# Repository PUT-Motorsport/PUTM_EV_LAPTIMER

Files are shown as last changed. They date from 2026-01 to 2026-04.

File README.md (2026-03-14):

# PUTM EV LAPTIMER

## About
This is standalone laptimer for Formula Student made on ESP32-S3 with ESP-IDF and LVGL. It provides simple way to monitor your lap times during trainings and vehicle tests.

## Features
- Measure lap time using one or two measure gates
- Save lap times on SD card
- Watch lap times on LCD or webpage
- Download .csv files with sorted lap times
- Add penalties from FSG Rules during laptime

## How to use
LCD GUI:
<br/>
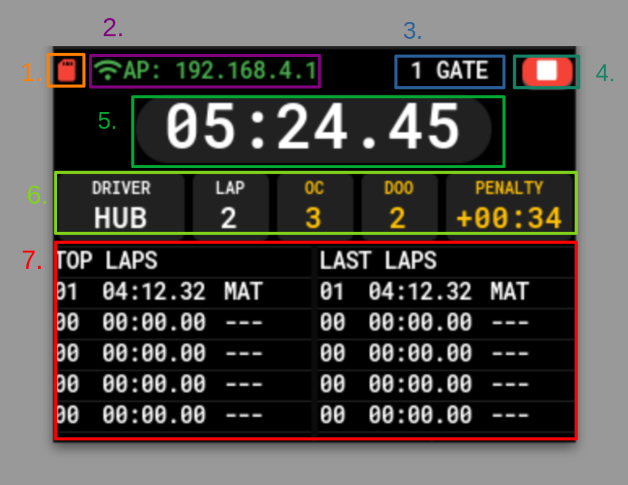
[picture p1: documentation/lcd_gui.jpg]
gui

1. SD card status
   - RED - not initialized
   - GREEN - initialized
2. WIFI status, mode and IP
   - RED - not initialized
   - GREEN - initialized
   - STA - station mode
   -  AP - access point mode
3. Gate mode
   - 1 GATE - like F1 race finish line, next lap starts automatically 
   - 2 GATES - one gate starts lap, second gate ends lap, then timer stops
4. RUN/STOP
   - RED - lap stopped
   - GREEN - lap in progress
5. Current lap time
6. Current lap info
   - DRIVER - tag of current driver
   - LAP - lap count
   - OC - number of FSG OC penalties
   - DOO - number of FSG DOO penalties
   - PENALTY - cumulated penalty time added to current lap time after finishing
7. Lap time lists
   <br/>
Similar interface can be accessed by connecting to a webpage hosted on ip address displayed on LCD. Moreover, on webpage you can download .csv files with lap times and change system configuration settings:
- Gate mode
- Wifi mode
- SSID and password of wifi network
- Date and time
- List of drivers
Those settings can be also changed by inserting SD card with [config file](firmware/main/config.txt)<br/>
## How to install
1. It's recommended to install ESP-IDF for Visual Studio Code with [this guide](https://github.com/espressif/vscode-esp-idf-extension/blob/master/README.md).
2. After cloning repository you should configure ESP-IDF project using
```
idf.py menuconfig
```
in CLI with activated ESP-IDF or 
```
>ESP-IDF: SDK Configuration Editor (Menuconfig)
```
in VSCode Command Palette, pin assignment and some other settings can be set in (Component config)/(PUTM EV Laptimer).
Default pin assignment is for ESP32-S3 and matches shield hardware used in this project.
<br/><br/>
3. Run
```
idf.py build
```
in CLI or
```
>ESP-IDF: Build Your Project
```
in Command Palette to build project
4. Easy way to quickly rebuild and flash project is to use command
```
>ESP-IDF: Build, Flash and Start a Monitor on Your Device
```
also available from VSCode status bar. You will also see program output in CLI. 
<br/>

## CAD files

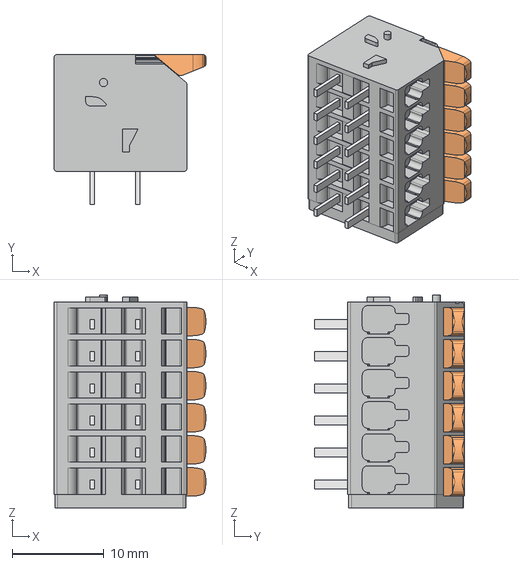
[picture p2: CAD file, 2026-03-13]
hardware/Model/2601-1106.stp
16.6 x 16.4 x 23.2 mm

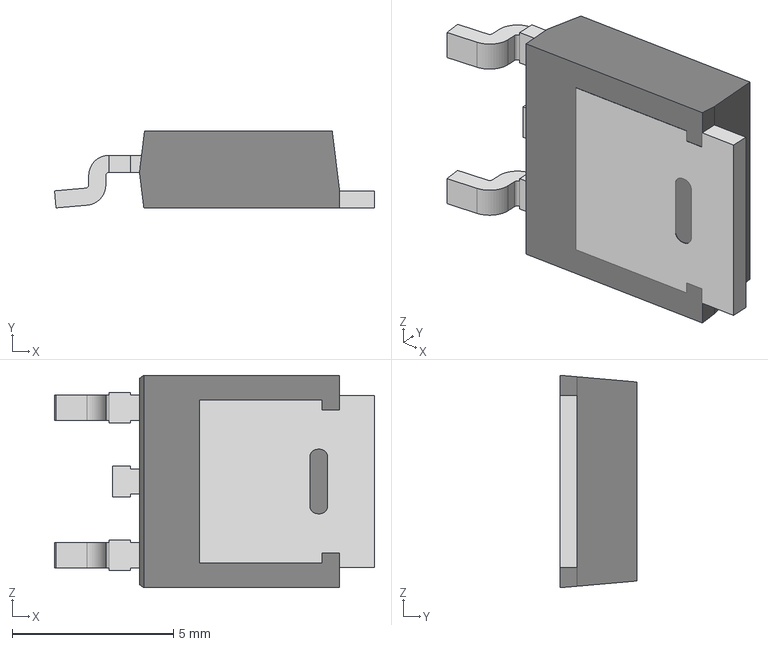
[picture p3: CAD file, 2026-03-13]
hardware/Model/VS-50WQ03FN-M3.stp
9.91 x 2.40 x 6.58 mm

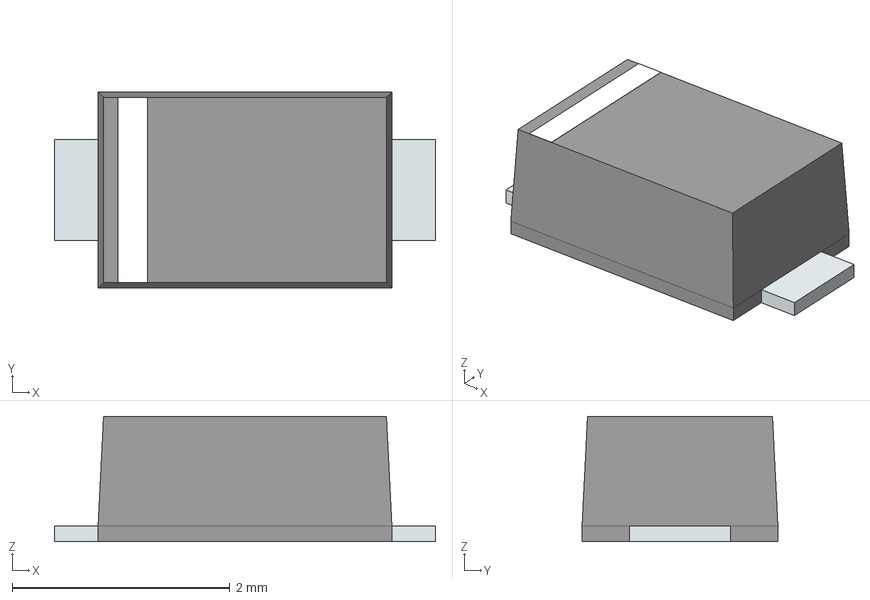
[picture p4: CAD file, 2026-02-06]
hardware/Model/MBR230S1F-7.stp
3.50 x 1.80 x 1.15 mm
PinKIdent
PinK
PinA

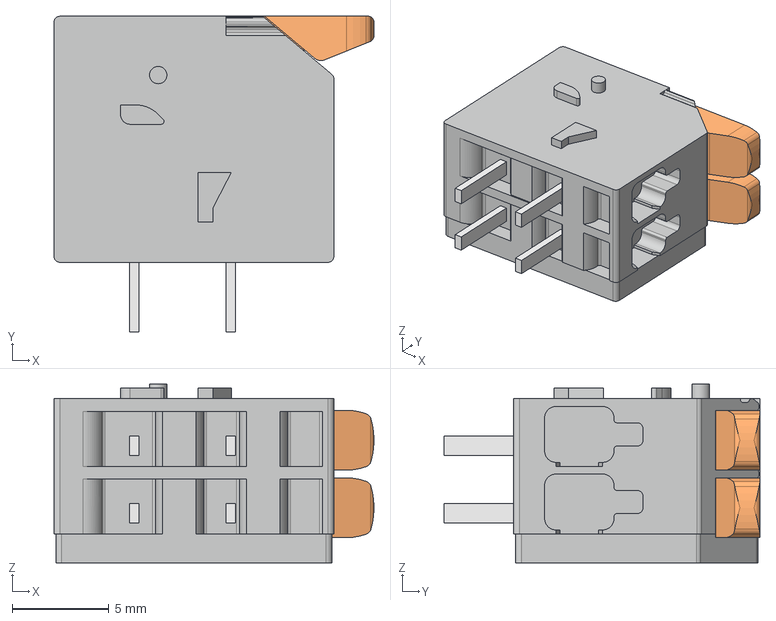
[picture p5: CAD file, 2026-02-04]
hardware/Model/2601-1102.stp
16.6 x 16.4 x 9.25 mm

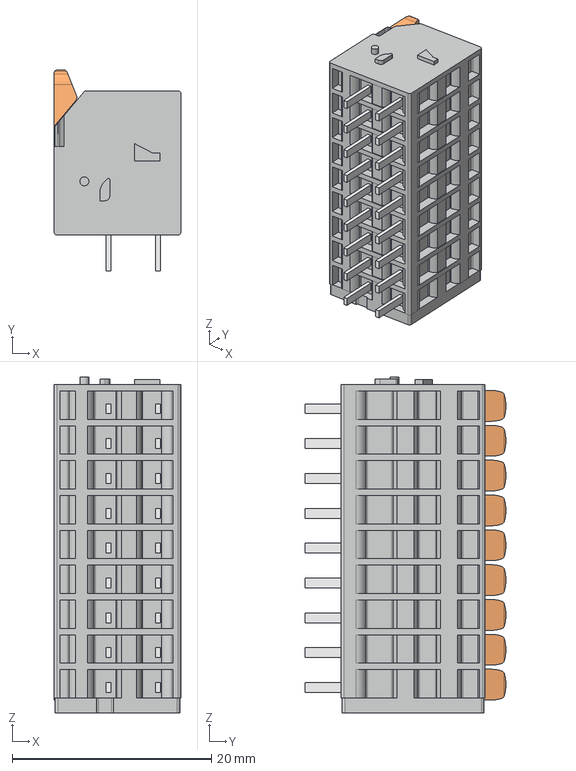
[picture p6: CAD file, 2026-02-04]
hardware/Model/2601-3109.stp
12.8 x 20.2 x 33.8 mm

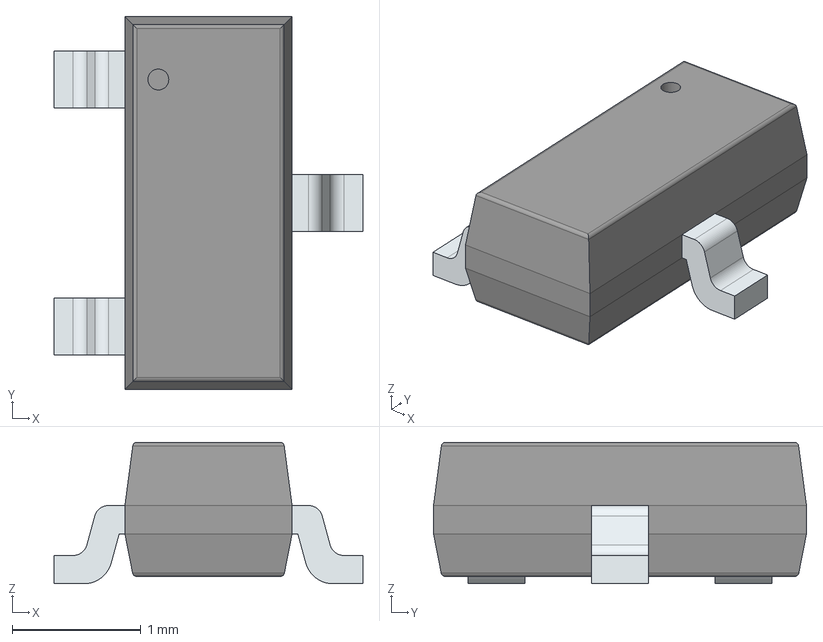
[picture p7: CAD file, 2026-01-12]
hardware/Model/DESD3V3L2BTQ-7.stp
2.40 x 2.90 x 1.10 mm
PinsArrayL
FilletPinR

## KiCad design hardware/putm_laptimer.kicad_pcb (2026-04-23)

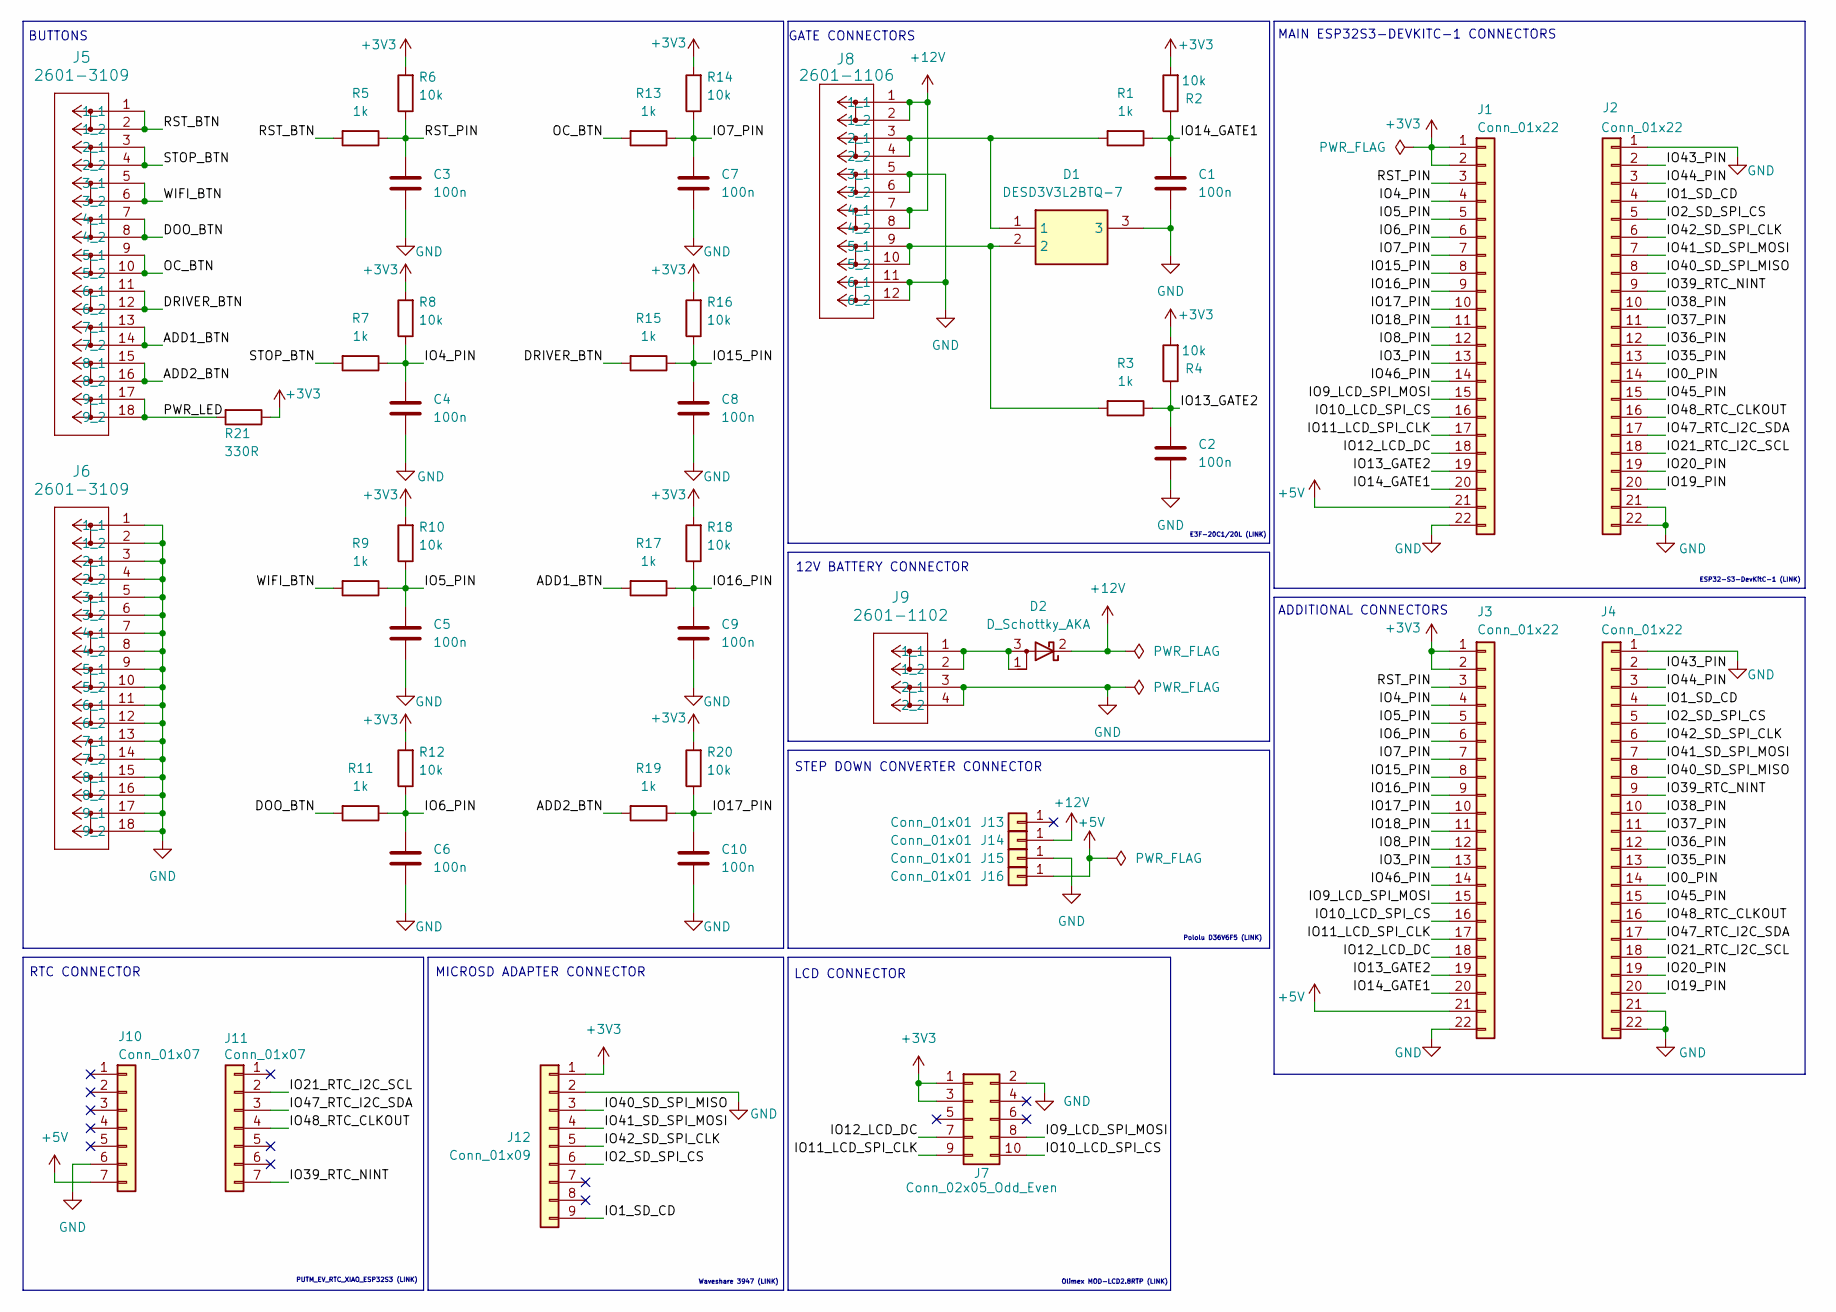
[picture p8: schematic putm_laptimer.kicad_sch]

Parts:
C1, C2, C3, C4, C5, C6, C7, C8, C9, C10: 100n; C_0603_1608Metric; Manufacturer_Part_Number GRM033R6YA104ME14D; Mouser/TME part number 81-GRM33R6YA104ME14D
D1: DESD3V3L2BTQ-7; SOT96P240X110-3N; Manufacturer_Part_Number DESD3V3L2BTQ-7; Mouser/TME part number 621-DESD3V3L2BTQ-7
D2: D_Schottky_AKA; VS50WQ03FNM3; Mouser/TME part number 844-50WQ03FN-M3
J1, J2, J3, J4: Conn_01x22; PinSocket_1x22_P2.54mm_Vertical; Manufacturer_Part_Number DS1023-1*40S21; Mouser/TME part number ZL262-40SG
J5, J6: 2601-3109; CONN9_2601-3109_WAG; Manufacturer_Part_Number 2601-3109; Mouser/TME part number sample
J7: Conn_02x05_Odd_Even; PinHeader_2x05_P2.54mm_Vertical; Manufacturer_Part_Number DS1013-10SSIB1-B-0; Mouser/TME part number ZL231-10PG
J8: 2601-1106; CONN6_2601-1106_WAG; Manufacturer_Part_Number 2601-1106; Mouser/TME part number sample
J9: 2601-1102; CONN2_2601-1102_WAG; Manufacturer_Part_Number 2601-1102; Mouser/TME part number sample
J10, J11: Conn_01x07; PinSocket_1x07_P2.54mm_Vertical; Manufacturer_Part_Number DS1023-1*7S21; Mouser/TME part number ZL262-7SG
J12: Conn_01x09; PinSocket_1x09_P2.54mm_Horizontal; Manufacturer_Part_Number DS1023-1*9S21; Mouser/TME part number ZL262-9SG
J13, J14, J15, J16: Conn_01x01; TestPoint_THTPad_D2.0mm_Drill1.0mm
R1, R3, R5, R7, R9, R11, R13, R15, R17, R19: 1k; R_0603_1608Metric; Manufacturer_Part_Number CR0603-FX-1001ELF; Mouser/TME part number 652-CR0603FX-1001ELF
R2, R4, R6, R8, R10, R12, R14, R16, R18, R20: 10k; R_0603_1608Metric; Manufacturer_Part_Number CR0603-FX-1002ELF; Mouser/TME part number 652-CR0603FX-1002ELF
R21: 330R; R_0603_1608Metric; Manufacturer_Part_Number CR0603-FX-3300ELF; Mouser/TME part number 652-CR0603FX-3300ELF

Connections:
+3V3: J1.1, J1.2, J3.1, J3.2, J7.1, J7.3, J12.1, R2.2, R4.2, R6.2, R8.2, R10.2, R12.2, R14.2, R16.2, R18.2, R20.2, R21.1
+5V: J1.21, J3.21, J10.7, J16.1
+12V: D2.2 (K), J8.1 (1_1), J8.2 (1_2), J8.7 (4_1), J8.8 (4_2), J14.1
/ADD1_BTN: J5.13 (7_1), J5.14 (7_2), R17.2
/ADD2_BTN: J5.15 (8_1), J5.16 (8_2), R19.2
/DOO_BTN: J5.7 (4_1), J5.8 (4_2), R11.2
/DRIVER_BTN: J5.11 (6_1), J5.12 (6_2), R15.2
/IO0_PIN: J2.14, J4.14
/IO1_SD_CD: J2.4, J4.4, J12.9
/IO2_SD_SPI_CS: J2.5, J4.5, J12.6
/IO3_PIN: J1.13, J3.13
/IO4_PIN: C4.1, J1.4, J3.4, R7.1, R8.1
/IO5_PIN: C5.1, J1.5, J3.5, R9.1, R10.1
/IO6_PIN: C6.1, J1.6, J3.6, R11.1, R12.1
/IO7_PIN: C7.1, J1.7, J3.7, R13.1, R14.1
/IO8_PIN: J1.12, J3.12
/IO9_LCD_SPI_MOSI: J1.15, J3.15, J7.8
/IO10_LCD_SPI_CS: J1.16, J3.16, J7.10
/IO11_LCD_SPI_CLK: J1.17, J3.17, J7.9
/IO12_LCD_DC: J1.18, J3.18, J7.7
/IO13_GATE2: C2.1, J1.19, J3.19, R3.1, R4.1
/IO14_GATE1: C1.1, J1.20, J3.20, R1.1, R2.1
/IO15_PIN: C8.1, J1.8, J3.8, R15.1, R16.1
/IO16_PIN: C9.1, J1.9, J3.9, R17.1, R18.1
/IO17_PIN: C10.1, J1.10, J3.10, R19.1, R20.1
/IO18_PIN: J1.11, J3.11
/IO19_PIN: J2.20, J4.20
/IO20_PIN: J2.19, J4.19
/IO21_RTC_I2C_SCL: J2.18, J4.18, J11.2
/IO35_PIN: J2.13, J4.13
/IO36_PIN: J2.12, J4.12
/IO37_PIN: J2.11, J4.11
/IO38_PIN: J2.10, J4.10
/IO39_RTC_NINT: J2.9, J4.9, J11.7
/IO40_SD_SPI_MISO: J2.8, J4.8, J12.3
/IO41_SD_SPI_MOSI: J2.7, J4.7, J12.4
/IO42_SD_SPI_CLK: J2.6, J4.6, J12.5
/IO43_PIN: J2.2, J4.2
/IO44_PIN: J2.3, J4.3
/IO45_PIN: J2.15, J4.15
/IO46_PIN: J1.14, J3.14
/IO47_RTC_I2C_SDA: J2.17, J4.17, J11.3
/IO48_RTC_CLKOUT: J2.16, J4.16, J11.4
/OC_BTN: J5.9 (5_1), J5.10 (5_2), R13.2
/PWR_LED: J5.17 (9_1), J5.18 (9_2), R21.2
/RST_BTN: J5.1 (1_1), J5.2 (1_2), R5.2
/RST_PIN: C3.1, J1.3, J3.3, R5.1, R6.1
/STOP_BTN: J5.3 (2_1), J5.4 (2_2), R7.2
/WIFI_BTN: J5.5 (3_1), J5.6 (3_2), R9.2
GND: C1.2, C2.2, C3.2, C4.2, C5.2, C6.2, C7.2, C8.2, C9.2, C10.2, D1.3, J1.22, J2.1, J2.21, J2.22, J3.22, J4.1, J4.21, J4.22, J6.1 (1_1), J6.2 (1_2), J6.3 (2_1), J6.4 (2_2), J6.5 (3_1), J6.6 (3_2), J6.7 (4_1), J6.8 (4_2), J6.9 (5_1), J6.10 (5_2), J6.11 (6_1), J6.12 (6_2), J6.13 (7_1), J6.14 (7_2), J6.15 (8_1), J6.16 (8_2), J6.17 (9_1), J6.18 (9_2), J7.2, J8.5 (3_1), J8.6 (3_2), J8.11 (6_1), J8.12 (6_2), J9.3 (2_1), J9.4 (2_2), J10.6, J12.2, J15.1
unnamed: D1.1, J8.3 (2_1), J8.4 (2_2), R1.2
unnamed: D1.2, J8.9 (5_1), J8.10 (5_2), R3.2
unnamed: D2.1 (A), D2.3 (A), J9.1 (1_1), J9.2 (1_2)

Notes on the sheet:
Waveshare 3947 (LINK)
E3F-20C1/20L (LINK)
12V BATTERY CONNECTOR
ADDITIONAL CONNECTORS
GATE CONNECTORS
MAIN ESP32S3-DEVKITC-1 CONNECTORS
Pololu D36V6F5 (LINK)
BUTTONS
STEP DOWN CONVERTER CONNECTOR
Olimex MOD-LCD2.8RTP (LINK)
PUTM_EV_RTC_XIAO_ESP32S3 (LINK)
MICROSD ADAPTER CONNECTOR
ESP32-S3-DevKitC-1 (LINK)
RTC CONNECTOR
LCD CONNECTOR

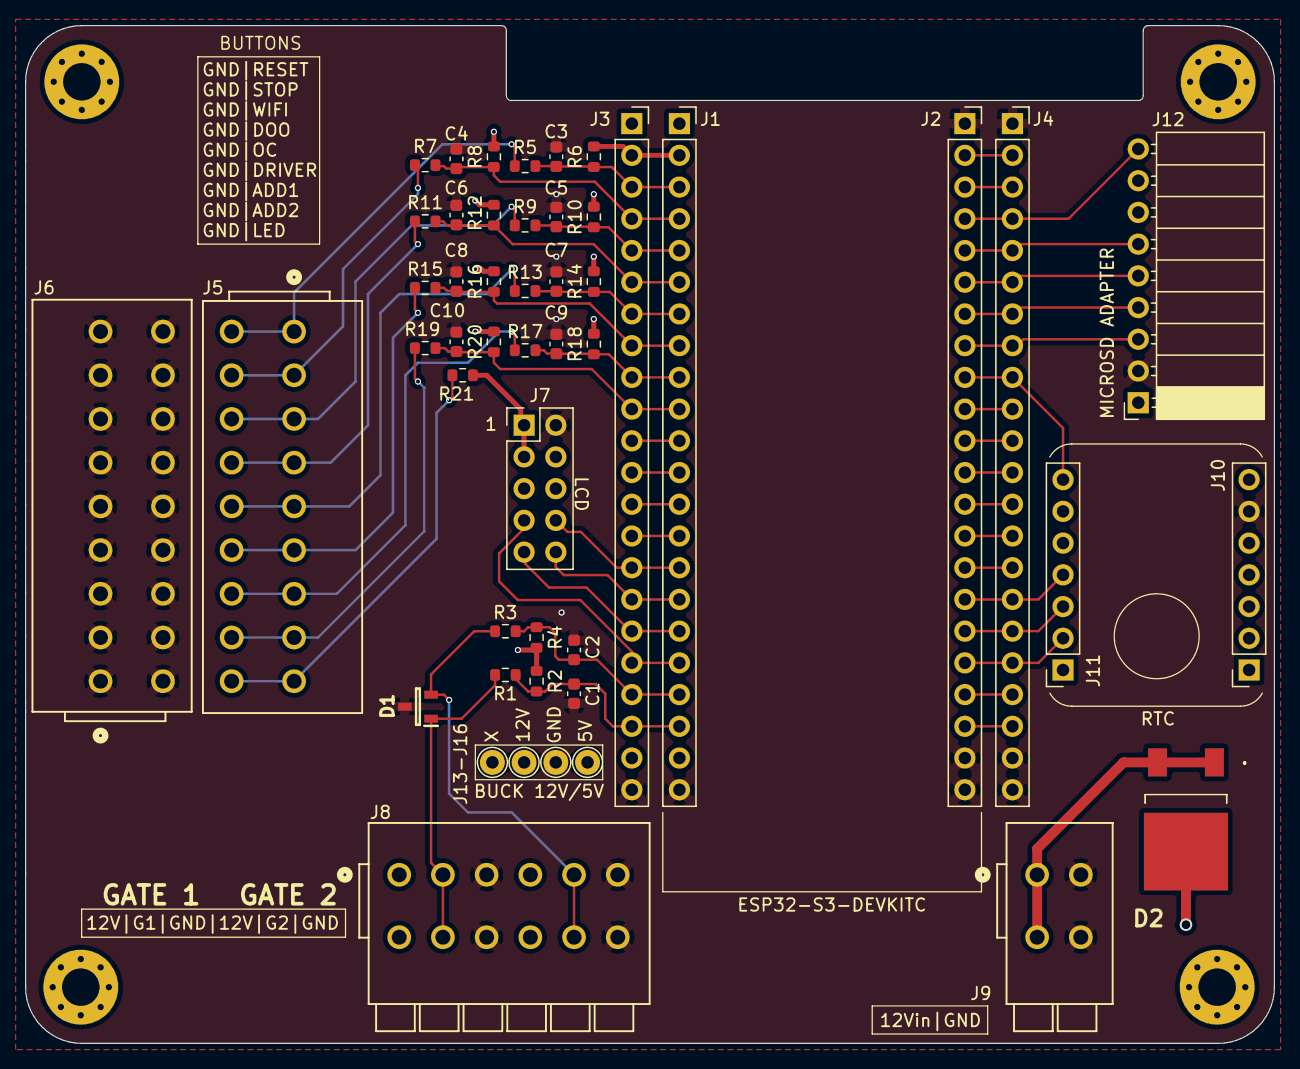
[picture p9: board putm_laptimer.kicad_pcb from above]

Board: 4 copper layers, 100.0 x 81.5 mm, 49 parts (0 on the bottom side), 53 nets.

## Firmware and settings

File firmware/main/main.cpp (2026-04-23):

#include "main.hpp"

#include "laptimer_task.hpp"
#include "wifi_task.hpp"

#ifdef CONFIG_TWO_GATE_WIRELESS_MASTER

#include "lcd_task.hpp"
#include "sdcard_task.hpp"

#endif

#include "gpio.h"
#include "timer.h"

void Laptime::reset() {

    this->time = 0;
    this->penalty_time = 0;
    this->doo_count = 0;
    this->oc_count = 0;
}

void Laptime::new_lap() {
    this->count++;
    this->reset();
}
void Laptime::convert_string_full(char laptime_str[LAPTIME_STR_LENGTH],
                                  size_t size) {
    if(laptime_str == NULL)
        return;

    if(this->time == 0) {
        snprintf(laptime_str, size, LAPTIME_STR_DEFAULT);
        return;
    }

    uint16_t mm = (this->time / 6000) % 60;
    uint16_t ss = (this->time / 100) % 60;
    uint16_t ms = this->time % 100;
    if(size == LAPTIME_STR_LENGTH)
        snprintf(laptime_str, size, "%02u, %02u:%02u:%02u", this->count, mm, ss,
                 ms);
}
void Laptime::convert_string_count(char count_str[COUNT_STR_LENGTH],
                                   size_t size) {
    if(count_str == NULL)
        return;

    if(this->time == 0) {
        snprintf(count_str, size, "--");
        return;
    }

    if(size >= COUNT_STR_LENGTH)
        snprintf(count_str, size, "%02u", this->count);
}
void Laptime::convert_string_time(char laptime_str[LAPTIME_STR_LENGTH],
                                  size_t size)

{
    if(laptime_str == NULL)
        return;

    if(this->time == 0) {
        snprintf(laptime_str, size, "--:--.--");
        return;
    }

    uint16_t mm = (this->time / 6000) % 60;
    uint16_t ss = (this->time / 100) % 60;
    uint16_t ms = this->time % 100;
    if(size == LAPTIME_STR_LENGTH)
        snprintf(laptime_str, size, "%02u:%02u:%02u", mm, ss, ms);
}
void Laptime::convert_string_penalty(char penalty_str[PENALTY_TIME_STR_LENGTH],
                                     size_t size) {
    if(penalty_str == NULL)
        return;

    if(this->time == 0) {
        snprintf(penalty_str, size, PENALTY_STR_DEFAULT);
        return;
    }

    uint16_t mm = (this->penalty_time / 6000) % 60;
    uint16_t ss = (this->penalty_time / 100) % 60;
    if(size >= 11) {
        snprintf(penalty_str, size, "+%02u:%02u", mm, ss);
    }
}

SemaphoreHandle_t config_mutex = xSemaphoreCreateMutex();
SemaphoreHandle_t laptime_lists_mutex = xSemaphoreCreateMutex();

QueueHandle_t laptime_saved_queue_sd =
    xQueueCreate(LAPTIME_LIST_SIZE_LOCAL, sizeof(Laptime));
QueueHandle_t laptime_current_queue_lcd = xQueueCreate(1, sizeof(Laptime));
QueueHandle_t laptime_current_queue_wifi = xQueueCreate(1, sizeof(Laptime));
QueueHandle_t ip_queue = xQueueCreate(1, sizeof(char[52]));

Config config_main;

std::array<Laptime, LAPTIME_LIST_SIZE_LOCAL> laptime_list_top;
std::array<Laptime, LAPTIME_LIST_SIZE_LOCAL> laptime_list_last;
std::array<Laptime, DRIVER_MAX_COUNT> laptime_list_driver;

volatile bool sd_active_flag = false;
volatile bool stop_flag = true;
volatile Wifi_reset wifi_reset_flag = WIFI_NO_RESET;
volatile wifi_mode_t wifi_mode_flag = WIFI_MODE_NULL;
volatile bool lists_refresh_lcd_flag = true;

/**
 * @brief Main task initializes core peripherals and creates program tasks
 */
extern "C" void app_main(void) {
    ESP_ERROR_CHECK(gpio_init());
    ESP_ERROR_CHECK(timer_init());
    // ESP_ERROR_CHECK(rtc_init());

    if(xSemaphoreTake(config_mutex, portMAX_DELAY)) {
        ESP_ERROR_CHECK(
            system_set_time(config_main.time_set, config_main.date_set));
        xSemaphoreGive(config_mutex);
    }

#ifdef CONFIG_TWO_GATE_WIRELESS_MASTER

    xTaskCreatePinnedToCore(sdcard_task, "SD_TASK", 8192, NULL, 0, NULL, 0);
    xTaskCreatePinnedToCore(lcd_task, "LCD_TASK", 8192, NULL, 2, NULL, 1);

#endif

    xTaskCreatePinnedToCore(laptimer_task, "LAPTIMER_TASK", 8192, NULL, 3, NULL,
                            0);
    xTaskCreatePinnedToCore(wifi_task, "WIFI_TASK", 4096, NULL, 1, NULL, 0);

    vTaskDelete(NULL);
}

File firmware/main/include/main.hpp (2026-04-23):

#pragma once

#include "defines.h"

#include "freertos/idf_additions.h"

#ifdef __cplusplus

#include <array>

/**
 * @defgroup defines
 * @brief Defines
 * @{
 */

/// @brief Size of local stored best/last laptime list
#define LAPTIME_LIST_SIZE_LOCAL 50

#define LAPTIME_STR_LENGTH 21

#define COUNT_STR_LENGTH 3

#define PENALTY_TIME_STR_LENGTH 11

#define PENALTY_COUNT_STR_LENGTH 25

#define DRIVER_MAX_COUNT 10

#define DRIVER_TAG_LENGTH 4

#define DRIVER_LIST_DEFAULT \
    { "---", "AAA", "BBB", "CCC" }

#define LAPTIME_STR_DEFAULT "--, --:--.--"
#define PENALTY_STR_DEFAULT "+00:00"
#define COUNT_STR_DEFAULT "0"

#define WIFI_MODE_DEFAULT WIFI_MODE_AP
#define WIFI_IP_DEFAULT "192.168.4.1"
#define WIFI_SSID_DEFAULT "PUTM_LAPTIMER"
#define WIFI_PASSWORD_DEFAULT "\0"
#define WIFI_CHANNEL_DEFAULT 1
#define WIFI_MAX_CONN_DEFAULT 3
#define TIMEOFDAY_STR_DEFAULT "21:37:00"
#define DATE_STR_DEFAULT "2026-01-01"

/**
 * @}
 * @defgroup types
 * @brief Types
 * @{
 */

/**
 * @brief Laptime class contains all properties of every laptime measurement.
 */

class Laptime {
  public:
    volatile uint16_t count = 1;
    volatile uint32_t time = 0;

    uint32_t penalty_time = 0;
    uint16_t doo_count = 0;
    uint16_t oc_count = 0;

    int8_t driver_id = 0;

    char timeofday[TIMEOFDAY_STR_LENGTH] = TIMEOFDAY_STR_DEFAULT;
    char date[DATE_STR_LENGTH] = DATE_STR_DEFAULT;

    void reset();
    void new_lap();

    /**
     * @brief Converts laptime count from int to string
     * @param laptime_str String for converted laptime
     * @param size Size of string
     */
    void convert_string_count(char count_str[COUNT_STR_LENGTH], size_t size);

    /**
     * @brief Converts laptime from int measured in 10ms to string that contains
     * count and time
     * @param laptime_str String for converted laptime
     * @param size Size of string
     */
    void convert_string_full(char laptime_str[LAPTIME_STR_LENGTH], size_t size);

    /**
     * @brief Converts laptime from int measured in 10ms to string that contains
     * only time
     * @param laptime_str String for converted laptime
     * @param size Size of string
     */
    void convert_string_time(char laptime_str[LAPTIME_STR_LENGTH], size_t size);

    /**
     * @brief Converts penalty time from int measured in 10ms to string that
     * contains penalty time
     * @param laptime_str String for converted laptime
     * @param size Size of string
     */
    void convert_string_penalty(char laptime_str[PENALTY_TIME_STR_LENGTH],
                                size_t size);
};

/**
 * @brief Contains list of three letter driver tags and number of drivers
 */
struct Driver_list {
    std::array<char[DRIVER_TAG_LENGTH], DRIVER_MAX_COUNT> list = {
        DRIVER_LIST_DEFAULT};
    uint8_t driver_count = 3;
};

/**
 * @brief Contains laptimer configuration settings for wifi, driver list, time
 * etc. Configuration is retrieved from sdcard or wifi webpage.
 */
struct Config {
    bool two_gate_mode = false;
    Driver_list driver_list;
    wifi_mode_t wifi_mode = WIFI_MODE_DEFAULT;
    char wifi_ssid[WIFI_SSID_STR_LENGTH] = WIFI_SSID_DEFAULT;
    char wifi_password[WIFI_PASSWORD_STR_LENGTH] = WIFI_PASSWORD_DEFAULT;
    char time_set[TIMEOFDAY_STR_LENGTH] = TIMEOFDAY_STR_DEFAULT;
    char date_set[DATE_STR_LENGTH] = DATE_STR_DEFAULT;
    // uint8_t wifi_channel = WIFI_CHANNEL_DEFAULT;
    // uint8_t wifi_max_connection = WIFI_MAX_CONN_DEFAULT;
    volatile uint32_t update = 0;
};

/**
 * @brief Possible states for resetting wifi webpage
 */
enum Wifi_reset {
    WIFI_NO_RESET,
    WIFI_RESET_CONFIG,
    WIFI_RESET_DEFAULTS,
};

/**
 * @}
 * @defgroup freertos
 * @brief FreeRTOS intertask communication
 * @{
 */

/**
 * @brief Access to config_main structure
 */
extern SemaphoreHandle_t config_mutex;

/**
 * @brief List of laptimes to save on sd card
 */
extern QueueHandle_t laptime_saved_queue_sd;

/**
 * @brief Queue passes current laptime from main logic laptimer_task to lcd_task
 * and wifi_task
 */
extern QueueHandle_t laptime_current_queue_lcd;
extern QueueHandle_t laptime_current_queue_wifi;

/**
 * @brief Mutex used by tasks to read: laptime_list_top, laptime_list_last,
 * laptime_list_driver
 */
extern SemaphoreHandle_t laptime_lists_mutex;

/**
 * @brief Queue used to send ip from wifi task to lcd task which displays ip
 * address on screen
 */
extern QueueHandle_t ip_queue;

/**
 * @}
 * @defgroup globals
 * @brief Global variables used by all tasks
 */

/**
 * @brief Main configuration, tasks refresh local configuration using
 * config_mutex
 */
extern Config config_main;

/**
 * @brief Laptimes sorted from fastest to slowest
 */
extern std::array<Laptime, LAPTIME_LIST_SIZE_LOCAL> laptime_list_top;

/**
 * @brief Laptimes sorted from newest to oldest
 */
extern std::array<Laptime, LAPTIME_LIST_SIZE_LOCAL> laptime_list_last;
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

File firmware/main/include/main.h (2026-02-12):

#pragma once

#include "freertos/idf_additions.h"
#include "esp_log.h"
#include "esp_err.h"
#include "sdkconfig.h"
#include <esp_wifi_types_generic.h>

/// @brief Size of local stored best/last laptime list
#define LAPTIME_LIST_SIZE_LOCAL 50

/// @brief Length of string needed to store converted laptime
#define LAPTIME_STR_LENGTH 21

#define PENALTY_TIME_STR_LENGTH 11

#define PENALTY_COUNT_STR_LENGTH 25

/// @brief Number of status flags displayed on LCD and webpage (gate mode, stop flag, sd flag)
#define STATUS_LIST_LENGTH 3

#define DRIVER_MAX_COUNT 10

#define DRIVER_TAG_LENGTH 4

#define TIMEOFDAY_STR_LENGTH 9
#define DATE_STR_LENGTH 11

#define WIFI_SSID_STR_LENGTH 32
#define WIFI_PASSWORD_STR_LENGTH 64

#define DRIVER_LIST_DEFAULT {"---", "AAA", "BBB", "CCC"}

#define LAPTIME_STR_DEFAULT "--, --:--.--"
#define PENALTY_STR_DEFAULT "+00:00"
#define COUNT_STR_DEFAULT "0"

#define WIFI_IP_DEFAULT
#define WIFI_SSID_DEFAULT "PUTM_LAPTIMER"
#define WIFI_PASSWORD_DEFAULT "\0"
#define WIFI_CHANNEL_DEFAULT 1
#define WIFI_MAX_CONN_DEFAULT 3
#define TIMEOFDAY_STR_DEFAULT "21:37:00"
#define DATE_STR_DEFAULT "2026-01-01"

#ifdef __cplusplus

class Laptime
{
public:
    volatile uint16_t count = 1;
    volatile uint64_t time = 0;

    uint32_t penalty_time = 0;
    uint16_t doo_count = 0;
    uint16_t oc_count = 0;

    int8_t driver_id = 0;

    char timeofday[TIMEOFDAY_STR_LENGTH] = TIMEOFDAY_STR_DEFAULT;
    char date[DATE_STR_LENGTH] = DATE_STR_DEFAULT;

    void reset();
    void new_lap();

    /**
     * @brief Converts laptime from int measured in 10ms to string that is ready to display
     * @param laptime_str String for converted laptime
     * @param size Size of string
     */
    void convert_string_full(char laptime_str[LAPTIME_STR_LENGTH], size_t size);

    void convert_string_time(char laptime_str[LAPTIME_STR_LENGTH], size_t size);

    void convert_string_penalty(char laptime_str[PENALTY_TIME_STR_LENGTH], size_t size);
};

struct Driver_list
{
    char list[DRIVER_MAX_COUNT][DRIVER_TAG_LENGTH] = DRIVER_LIST_DEFAULT;
    uint8_t driver_count = 3;
};

struct Config
{
    bool two_gate_mode = false;
    Driver_list driver_list;
    wifi_mode_t wifi_mode = WIFI_MODE_STA;
    char wifi_ssid[WIFI_SSID_STR_LENGTH] = WIFI_SSID_DEFAULT;
    char wifi_password[WIFI_PASSWORD_STR_LENGTH] = WIFI_PASSWORD_DEFAULT;
    char time_set[TIMEOFDAY_STR_LENGTH] = TIMEOFDAY_STR_DEFAULT;
    char date_set[DATE_STR_LENGTH] = DATE_STR_DEFAULT;
    // uint8_t wifi_channel = WIFI_CHANNEL_DEFAULT;
    // uint8_t wifi_max_connection = WIFI_MAX_CONN_DEFAULT;
};

enum Wifi_reset
{
    WIFI_RESET_CONFIG,
    WIFI_RESET_DEFAULTS,
};

#endif

/**
 * @defgroup freertos
 * @brief FreeRTOS intertask communication
 */

extern SemaphoreHandle_t config_mutex;

extern SemaphoreHandle_t wifi_reset_queue;

/**
 * @ingroup freertos
 * @brief Queue passes laptimes from main logic laptimer_task to sdcard_task
 */
extern QueueHandle_t laptime_saved_queue_sd;

/**
 * @ingroup freertos
 * @brief Queue passes current laptime from main logic laptimer_task to lcd_task and wifi_task
 */
extern QueueHandle_t laptime_current_queue_lcd;
extern QueueHandle_t laptime_current_queue_wifi;

/**
 * @ingroup freertos
 * @brief Semaphore allows lcd_task and wifi_task to read stored laptime lists
 */
extern SemaphoreHandle_t laptime_lists_mutex;

/**
 * @ingroup freertos
 * @brief Queue passes active status flags from main logic laptimer_task to lcd_task and wifi_task
 * bool[0] - two_gates_mode
 * bool[1] - stop_flag
 * bool[2] - sdcard_flag
 */
extern QueueHandle_t laptime_status_queue_lcd;
extern QueueHandle_t laptime_status_queue_wifi;

extern QueueHandle_t ip_queue;
extern QueueHandle_t wifi_mode_queue;

#ifdef __cplusplus

extern Config config_main;

extern Laptime laptime_list_top[LAPTIME_LIST_SIZE_LOCAL];
extern Laptime laptime_list_last[LAPTIME_LIST_SIZE_LOCAL];
extern Laptime laptime_list_driver[DRIVER_MAX_COUNT];
#endif

extern bool sd_active_flag;

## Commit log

2025-11-26 fix includes and macros
    [laptimer_task.cpp, main.cpp, main.h]
2025-11-27 fix font buffer issue
    [main.cpp]
2025-11-30 - changed lcd gui elements positions - fixed sdcard spi dma initialization bug
    [sdcard.c]
2025-12-01 fixed sdcard save format
    [laptimer_task.cpp]
2025-12-02 fixed sdcard reinitialization bug
    [sdcard.c, sdcard.h]
2025-12-03 added working buttons for adding/deleting time penalties from fsg rules
2025-12-05 working current penalty display on lcd
2025-12-07 updated pinout for esp32s3 and added pinout configuration through kconfig
2025-12-07 added download csv button to website
2025-12-08 fixed status flags bug
    [laptimer_task.cpp, main.cpp, main.h]
2025-12-09 sdcard now uses card detect pin on new adapter that allows to easier initialize and deinitialize
2025-12-10 added button for switching drivers, changed button hold logic
2025-12-10 added current driver display on lcd
2025-12-10 added laptime lists driver tag color display on lcd
2025-12-12 added drivers display on webpage
2025-12-12 added drivers on website with best laptimes and sum of penalties
2025-12-14 updated sdkconfig for esp32s3
2025-12-14 updated sdcard save format to save laptime penalties and drivers
2025-12-14 added reading driver list from sdcard
2025-12-15 fixed sdcard driver list reading bug, added local driver lists in tasks
    [laptimer_task.cpp, main.cpp, main.h]
2025-12-15 fixed wifi webpage bug
    [laptimer_task.cpp, main.cpp, main.h]
2025-12-17 added internal pull down for reset btn
    [gpio.c]
2025-12-21 - fixed pinout - created structure for config - added station mode to wifi
    [gpio.c, laptimer_task.cpp, main.cpp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]
2025-12-21 deleted lap mode button and added wifi reset button
2025-12-22 added wifi reset to safe values on button long press
    [laptimer_task.cpp, main.cpp, main.h]
2025-12-28 reduced spi speed
2026-01-12 added schematics and pcb prototype
2026-01-12 added pcb files
    [2091-1372.stp, DESD3V3L2BTQ-7.stp, putm_laptimer.kicad_pcb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]
2026-01-12 changed pinout to match pcb
2026-01-15 deleted buttons on board and added hawrin connector
    [M80-5001605.stp, putm_laptimer.kicad_pcb, putm_laptimer.kicad_sch]
2026-01-17 added rtc connectors to schematics
    [putm_laptimer.kicad_sch]
2026-01-18 placed rtc connectors on pcb
    [putm_laptimer.kicad_pcb, putm_laptimer.kicad_sch]
2026-01-18 changed harwin connector to connect power led, updated cleareance and net width
    [M80-5001805.stp, putm_laptimer.kicad_pcb, putm_laptimer.kicad_sch]
2026-01-19 changed element placement
    [putm_laptimer.kicad_pcb]
2026-01-25 Added connectors for step-up converter and changed wago connectors to 6-pin
    [2091-1376.stp, putm_laptimer.kicad_pcb, putm_laptimer.kicad_sch]
2026-01-26 Changed layout
    [putm_laptimer.kicad_pcb]
2026-01-26 Fixed connector footprint
    [putm_laptimer.kicad_pcb, putm_laptimer.kicad_sch]
2026-01-26 Fixed footprint refrence on silkscreen
    [putm_laptimer.kicad_pcb, putm_laptimer.kicad_sch]
2026-01-26 Added board dimensions
    [putm_laptimer.kicad_pcb]
2026-01-31 Fixed borders
    [putm_laptimer.kicad_pcb]
2026-01-31 Added modules info and links to connector schematics
    [putm_laptimer.kicad_pcb, putm_laptimer.kicad_sch]
2026-02-01 Fixed routing
    [putm_laptimer.kicad_pcb]
2026-02-02 Changed layout, changed gate connector, added 12V battery connector and buck converter pins
    [734-162.stp, 734-163.stp, putm_laptimer.kicad_pcb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]
2026-02-02 Fixed schematics
    [putm_laptimer.kicad_pcb, putm_laptimer.kicad_sch]
2026-02-03 Fixed pcb layout
    [putm_laptimer.kicad_pcb, putm_laptimer.kicad_sch]
2026-02-04 Increased buck converter pin hole diameter
    [putm_laptimer.kicad_pcb]
2026-02-04 Changed connectors
    [2601-1102.stp, 2601-1103.stp, 2601-3109.stp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]
2026-02-06 Added pwr flags on battery connector and fixed wago connector footprint malformed courtyard
    [putm_laptimer.kicad_pcb, putm_laptimer.kicad_sch]
2026-02-06 Added reverse polarity protection diode, deleted unused footprints
    [2091-1372.stp, 2091-1376.stp, 734-162.stp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]
2026-02-08 Changed esp32 connector
    [putm_laptimer.kicad_pcb, putm_laptimer.kicad_sch]
2026-02-08 Added part numbers
    [putm_laptimer.kicad_sch]
2026-02-08 Fixed silkscreen text size
    [putm_laptimer.kicad_pcb, putm_laptimer.kicad_sch]
2026-02-09 Fixed connector placing
    [putm_laptimer.kicad_pcb, putm_laptimer.kicad_sch]
2026-02-09 Fixed silkscreen text
    [putm_laptimer.kicad_pcb]
2026-02-09 Fixed trace routing
    [putm_laptimer.kicad_pcb]
2026-02-11 Fixed wago connector place, resized board
    [putm_laptimer.kicad_pcb]
2026-02-11 Changed lcd connector model
    [putm_laptimer.kicad_pcb, putm_laptimer.kicad_sch]
2026-02-11 Changed pull up ressistor trace
    [putm_laptimer.kicad_pcb]
2026-02-11 Fixed silkscreen
    [putm_laptimer.kicad_pcb]
2026-02-12 Changed capactitor model
    [putm_laptimer.kicad_sch]
2026-02-12 Changed buck converter position
    [putm_laptimer.kicad_pcb]
2026-02-12 Fixed silkscreen overlap
    [putm_laptimer.kicad_pcb]
2026-03-13 Fixed bom table
    [putm_laptimer.kicad_sch]
2026-03-13 Table part numbers fix
    [putm_laptimer.kicad_sch]
2026-03-13 Added second gate connector
    [2601-1103.stp, 2601-1106.stp, putm_laptimer.kicad_pcb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]
2026-03-13 Changed reverse polarity protection schottky diode
    [VS-50WQ03FN-M3.stp, putm_laptimer.kicad_pcb, putm_laptimer.kicad_sch]
2026-03-13 Changed silkscreen info tables
    [putm_laptimer.kicad_pcb]

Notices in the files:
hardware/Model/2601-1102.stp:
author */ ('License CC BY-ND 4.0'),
